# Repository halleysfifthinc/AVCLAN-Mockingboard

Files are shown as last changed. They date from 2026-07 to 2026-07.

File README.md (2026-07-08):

# AVCLAN Mockingboard

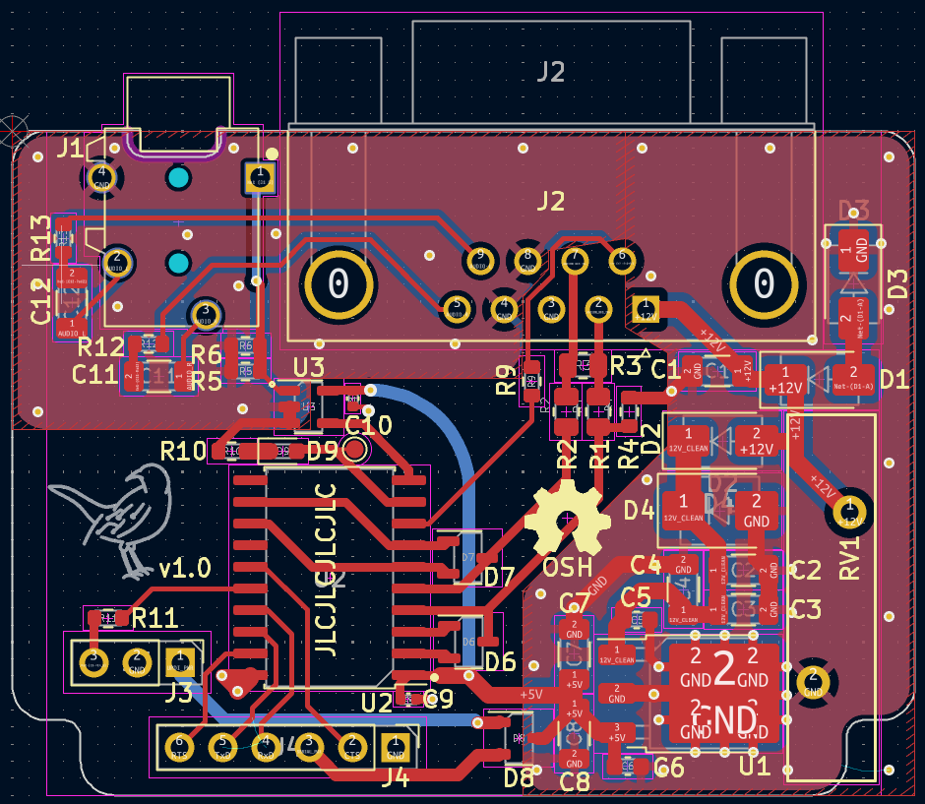
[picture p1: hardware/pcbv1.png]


This project adds an aux in to the stock head unit of compatible Toyota vehicles by emulating an external CD changer. The Mockingboard communicates with the head unit over the AVC-LAN bus, Toyota's name for their messaging protocol over the NEC (now Renesas) IEBus. Also included is a Wireshark dissector for IEBus and AVC-LAN. AVC-LAN is sparsely documented publicly; this dissector collects what's known from prior art alongside my own findings.

# Features:

- Select/switch between internal CD player and mockingboard by pressing the "CD" button (repeated presses toggle between internal and external CD players)
- Generally complete handling of physical interface (track next/prev, fast-forward/rewind, track/disk repeat and random; "scan" button and change disc buttons are currently unimplemented for lack of use/purpose)
- Play/pause, next/prev control of connected phones via headset functions (mimicing the button press on a wired headset; requires phone support and connection using a TRRS aux cable)

## Future plans (Mockingboard v2)

- Bluetooth functionality
  - "Scan" button repurposed to enter bluetooth pairing mode
  - Button actions (play/pause, track skip, ff/rw, \[disc\] repeat/shuffle) mapped to AVRCP
  - Song info/status (time, etc) relayed to head-unit (i.e. time display matches actual song/audio time)
- Redesigned hardware based on RPi Pico 2W (RP2350 + Bluetooth)
  - PIO used to implement:
    - AVCLAN comms
    - I2S audio
  - Dual audio input options (aux in, bluetooth)
    - Switched audio jack to sense aux plug presence
  - Audio codec with differential output (better rejection of electrical noise, e.g. from adjacent AVCLAN bus lines)
  - Switching regulator (easier assembly)
  - CAN transceiver
    - TX/RX connected to different diodes (or different pads of a single dual/multicolor LED package) for observability

# Helpful links/prior art:

- IEBus/AVCLAN decoder and message dumps (inc. a CD changer) for Sigrok
    - https://github.com/sigrokproject/sigrok-test/pull/22
    - https://github.com/sigrokproject/sigrok-dumps/pull/43
    - https://github.com/sigrokproject/libsigrokdecode/pull/106
- https://web.archive.org/web/20230319000356/http://softservice.com.pl/corolla/avc/avclan.php
- https://web.archive.org/web/20040617005106/http://www.interfacebus.com/Design_Connector_IEbus.html
- https://web.archive.org/web/2/https://old.pinouts.ru/Car-Stereo-Toyota-Lexus/Toyota_1990-2002_CD_Chang_pinout.shtml
- https://web.archive.org/web/20240519043021/https://pop.fsck.pl/hardware/toyota-corolla.html
- https://github.com/GadgetNutt/AVC-LAN-Module-Builder

# Firmware

### Building

#### With VS Code:

1. Install VS Code and Docker
    - Required extensions: Dev Containers
2. Open repo in VS code and wait for notification asking to re-open in dev container.
    - Wait for container to build and extensions to install
3. Select CMake build configuration
4. Start developing!

#### Natively/without VS Code Dev Containers
1. Install avr-gcc >= v13.1, binutils >= v2.39, cmake >= v3.24
2. Configure cmake with a hardware-target preset, `cmake --list-presets` to discover options
    - Trigger builds with e.g. `cmake --build out/build/attiny3216`
3. Start developing!

# Hardware

## First generation

See [here](hardware/mockingboard-v1/README.md) for details.

## Second generation

Under development!

# Protocol reverse-engineering

The "scripts/packet-analysis" folder contains a [Wireshark](https://www.wireshark.org/) [Lua plugin](https://www.wireshark.org/docs/wsdg_html_chunked/wsluarm.html) that defines a dissector for IEBUS and AVC-LAN messages.

The dissector's `known_devices` / `known_actions` tables are the source of truth
for AVC-LAN device and action names. `scripts/sync_avclan_enums.py` reconciles
the firmware's C++ `Device` / `Action` enums (and every reference under `src/`)
against them, matching by value so renamed values are propagated. It runs as a
pre-commit hook — the top-level CMake configure step points `core.hooksPath` at
`.githooks/`, so `cmake --preset …` activates it automatically (opt out with
`-DINSTALL_GIT_HOOKS=OFF`; `git commit --no-verify` bypasses one commit). The
hook only reports drift; run `scripts/sync_avclan_enums.py --fix` to apply, and
`--lint` to check that the dissector's own names are valid identifiers.

# License

The firmware for this project is licensed under the [GNU GPLv3](https://www.gnu.org/licenses/gpl-3.0.html). The AVR-Attiny3216 hardware target depends on a vendored [MIT](https://spdx.org/licenses/MIT) licensed [UART library](https://github.com/jnk0le/AVR-UART-lib), and the [MPL-2.0](https://www.mozilla.org/MPL/2.0/) licensed [avr-libstdcpp](https://github.com/modm-io/avr-libstdcpp/) C++ STL subset.
The hardware is licensed under the [Solderpad Hardware License v2.1](http://solderpad.org/licenses/SHL-2.1/), a
wraparound license to the [Apache License 2.0](https://apache.org/licenses/LICENSE-2.0.txt).

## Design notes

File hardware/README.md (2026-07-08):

# Hardware

## Cable harness

I ordered a [cable harness](https://www.amazon.com/dp/B01EUZ8CFU) from Amazon to acquire the head-unit side connector. I then cut the male end off a DB9 cable and connected the wires according to the following cable harness diagram:

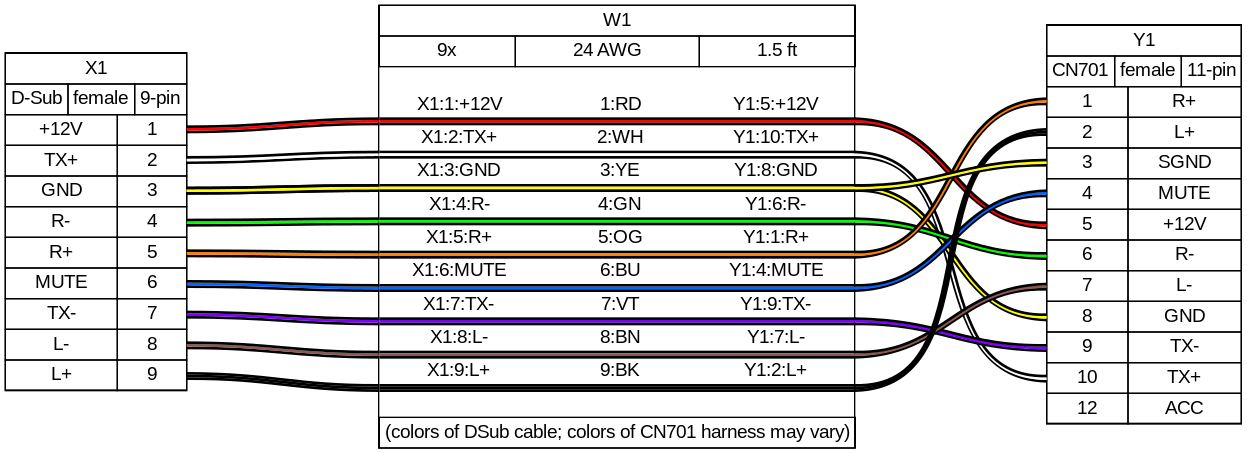
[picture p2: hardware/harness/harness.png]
cable diagram


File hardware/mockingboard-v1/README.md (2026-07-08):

# Hardware

I ordered the boards partially assembled from JLCPCB (to keep costs down, I ordered and soldered some non-standard/stocked parts myself.)

The non-populated/assembled BOM is:

| Mouser #: | Mfr. #: | Desc.: | Order Qty. | Unit Price (USD) |
| --- | --- | --- | --- | --- |
| 579-ATTINY3216-SNR  | ATTINY3216-SNR | 8-bit Microcontrollers - MCU 8-bit Microcontrollers - MCU 20MHz, 32KB, SOIC20, Ind 105C, Green, T&R | 1 | $1.27 |
| 523-L717SDE09PA4CH4 | L717SDE09PA4CH4F | D-Sub Standard Connectors D-Sub Standard Connectors D SUB R/A | 1 | $1.98 |
| 490-SJ-43514 | SJ-43514 | Phone Connectors Phone Connectors audio jack, 3.5 mm, rt, 4 conductor, through hole, 0 switches | 1 | $1.35 |
| 667-ERZ-V20D220 | ERZ-V20D220 | Varistors Varistors 22V 2000A ZNR SUR ABSORBER 20MM | 1 | $1.24 |
| 538-22-28-8093 | 22-28-8093 | Headers & Wire Housings Headers & Wire Housings 2.54MM BREAKAWAY RA 9 CKT Gold | 2 | $0.76 |
| 865-XC6701D502JR-G  | XC6701D502JR-G | LDO Voltage Regulators LDO Voltage Regulators 28V High Speed Voltage Regulator | 1 | $1.36 |
| 563-EXN-23350-BK | EXN-23350-BK | Enclosures, Boxes, & Cases Enclosures, Boxes, & Cases Extruded Aluminum Enclosure Black (1.4 X 2.7 X 1.9 In) | 1 | $14.40 |

An earlier version of the board* lacked cutouts in the corners to fit the ends of the intended housing, so I haven't used the listed enclosure (yet).

*Only version of the board I have ordered so far.

### Flashing

The CMake target `flash` uses the AVRDude utility using the "serialupdi" programmer type. I use a [USB => Serial converter](https://www.adafruit.com/product/5335) with the Rx and Tx lines connected, using one of the options described [by SpenceKonde here](https://github.com/SpenceKonde/AVR-Guidance/blob/master/UPDI/jtag2updi.md).

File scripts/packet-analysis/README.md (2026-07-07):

# Packet analysis with Wireshark

- Install the Lua IEBUS/AVCLAN packet dissector to the Wireshark Lua Plugins folder
    - Look in Help > About Wireshark dialog, Folders tab, "Personal Lua Plugins". It was `~/.local/lib/wireshark/plugins` for me, but it didn't exist until I manually created it.
    - Copy or link `avclan_plugin.lua` to the Wireshark Lua Pluginds folder
        - Linking is more convenient if modifying/developing the dissector
          `ln -s $(pwd)/avclan_plugin.lua ~/.local/lib/wireshark/plugins/avclan_plugin.lua`
- The bridge script ([extcap/avclan-pcap.py](extcap/avclan-pcap.py)) needs Python 3 and, for live capture only, [pyserial](https://pypi.org/project/pyserial/). Install pyserial so the `python3` that Wireshark runs can import it (e.g. `pip install pyserial`, or your distro's `python3-serial`). The `--convert` mode and the Wireshark interface listing work without it. (Alternatively, run the script via [uv](https://docs.astral.sh/uv/) — `uv run --script extcap/avclan-pcap.py …` — which resolves the inline PEP 723 dependency automatically; but the GUI extcap uses plain `python3`, so the install above is what makes capture work there.)

## Live capture (Wireshark GUI)

The easiest way to stream packets is as an [extcap](https://www.wireshark.org/docs/man-pages/extcap.html) interface, which appears right in Wireshark's capture list:

- Make the script executable and link it into Wireshark's **Personal Extcap path** (Help > About Wireshark, Folders tab — alongside the Lua plugin folder above):

      chmod +x extcap/avclan-pcap.py
      mkdir ~/.local/lib/wireshark/extcap
      ln -s "$(pwd)/extcap/avclan-pcap.py" ~/.local/lib/wireshark/extcap/avclan-pcap.py

- Restart Wireshark. **AVC-LAN (serial)** now shows up in the interface list. The script autodetects a USB-UART adapter; to override, open the interface's gear/options and set the serial port. Click the shark fin to start. Wireshark owns the process, so stopping the capture (or unplugging the adapter) shuts the bridge down cleanly.

## Live capture (command line)

If you prefer the pipe, the same script works as a plain producer:

    ./extcap/avclan-pcap.py --port /dev/ttyUSB0 | wireshark -k -i -

Omit `--port` (or pass `--port auto`) to autodetect the adapter.

## Converting a text log to pcap

The Mockingboard's text-mode REPL output (e.g. [msgdumps/myfile.txt](msgdumps/myfile.txt)) can be turned into a capture file offline:

    ./extcap/avclan-pcap.py --convert msgdumps/myfile.txt -o out.pcap

Use a `.pcapng` extension to get pcapng instead (requires `editcap`, which ships with Wireshark). With the Lua dissector installed, the result is recognized and dissected as IEBUS/AVCLAN packets.

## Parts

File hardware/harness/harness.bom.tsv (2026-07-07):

Id | Description | Qty | Unit | Designators
1 | Cable, 9 x 24 AWG | 1.5 | ft | W1
2 | Connector, CN701, female, 11 pins | 1 |  | Y1
3 | Connector, D-Sub, female, 9 pins | 1 |  | X1

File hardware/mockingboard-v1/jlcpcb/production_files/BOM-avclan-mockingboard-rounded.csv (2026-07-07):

Comment | Designator | Footprint | LCSC
SM6T15A | D4 | D_SMB | C118275
BAT54A,215 | D7 | SOT-23-3 | C130910
10u 50V | C2,C3,C4 | C_1206_3216Metric | C13585
SS210 | D1,D2 | D_SMA | C14996
1u 50V | C5,C6 | C_0603_1608Metric | C15849
10k | R4,R5,R6,R7,R8,R9 | R_0603_1608Metric | C17414
120 | R3 | R_0805_2012Metric | C17437
15 | R12,R13 | R_0603_1608Metric | C22810
KT-0603R | D9 | LED_0603_1608Metric | C2286
470 | R10,R11 | R_0603_1608Metric | C23179
4u7 | C10,C9 | C_0402_1005Metric | C23733
180 | R1,R2 | R_0805_2012Metric | C25270
1SMAF4742A | D3 | D_SMA | C3013762
BAT54C,215 | D6,D8 | SOT-23-3 | C37704
74LVC1G66 | U3 | SOT-23-5 | C5375974
3V3 | D10 | D_MiniMELF | C8056
1n 100V | C1 | C_1206_3216Metric | C9196
47u 10V | C11,C12,C7,C8 | C_1206_3216Metric | C96123

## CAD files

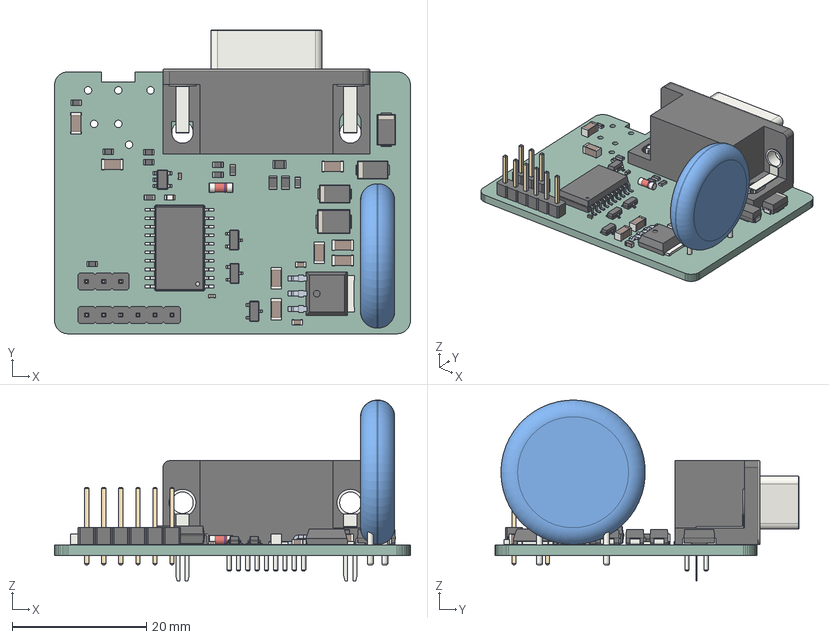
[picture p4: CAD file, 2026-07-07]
hardware/mockingboard-v1/avclan-mockingboard-rounded.step
53.0 x 45.2 x 26.9 mm
avclan-mockingboard-rounded PCB

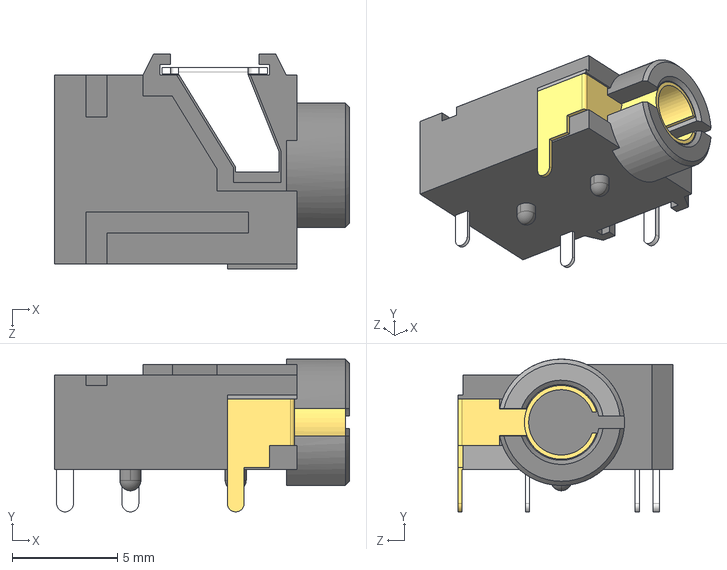
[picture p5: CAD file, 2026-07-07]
hardware/mockingboard-v1/CUI_DEVICES_SJ-43514.step
14.0 x 7.25 x 10.2 mm

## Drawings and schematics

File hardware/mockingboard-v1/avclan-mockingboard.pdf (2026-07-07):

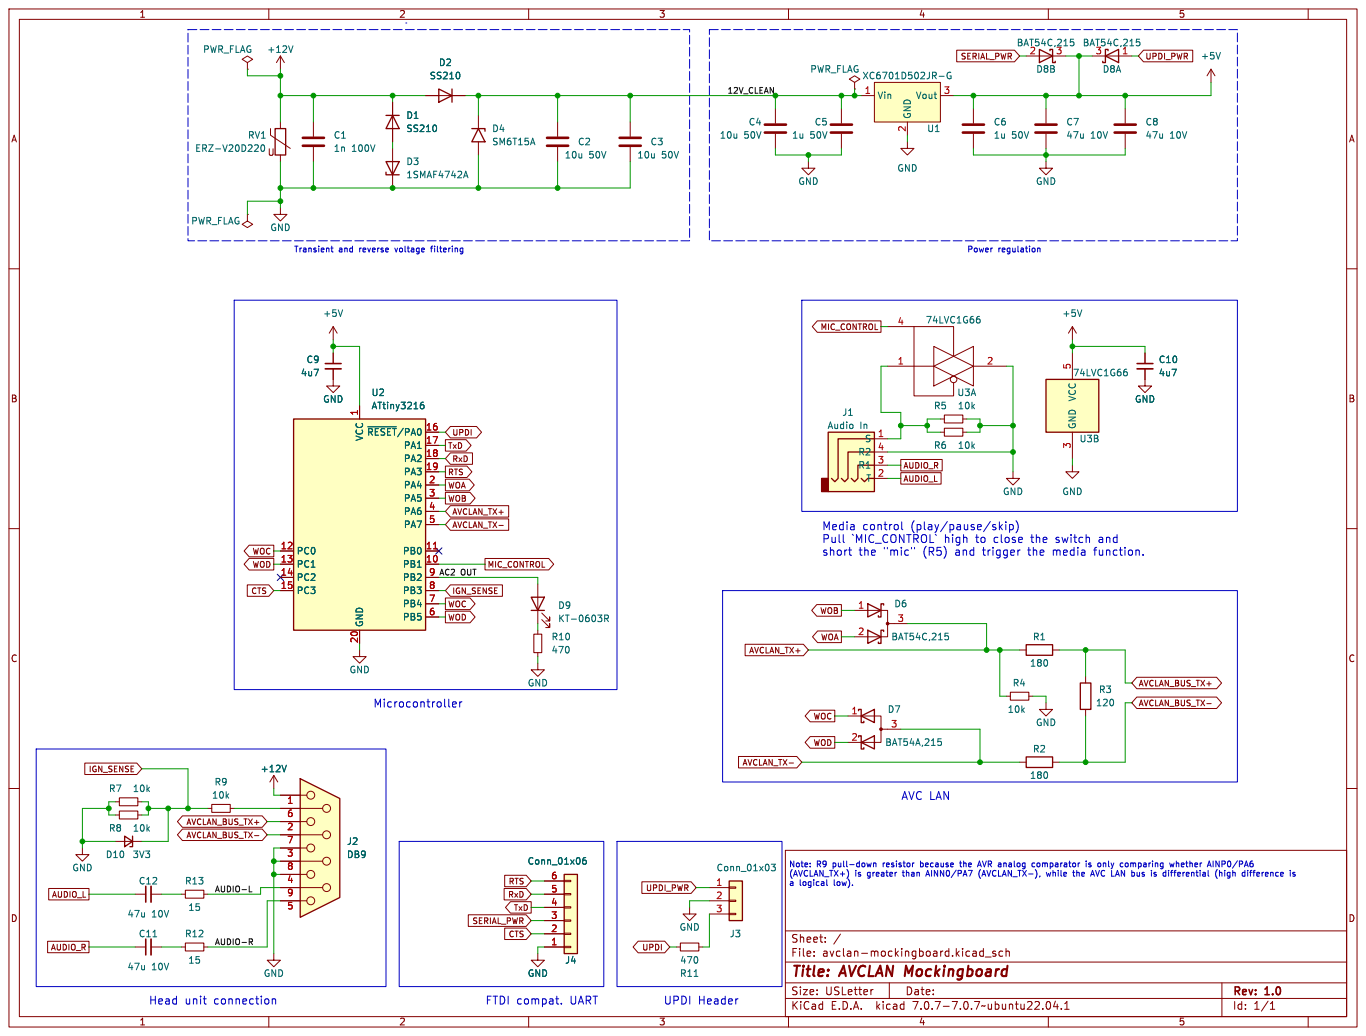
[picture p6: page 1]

1 PB1 10 PB0 11 PC0 12 PC1 13 PC2 14 PC3 15 ~{RESET}/PA016 PA1 17 PA2 18 PA3 19 PA4 2 GND 20 PA5 3 PA6 4 PA7 5 PB5 6 PB4 7 PB3 8 PB2 9 U2ATtiny3216 GND GND

File: avclan-mockingboard.kicad_sch Sheet: /
Id: 1/1 Title: AVCLAN Mockingboard

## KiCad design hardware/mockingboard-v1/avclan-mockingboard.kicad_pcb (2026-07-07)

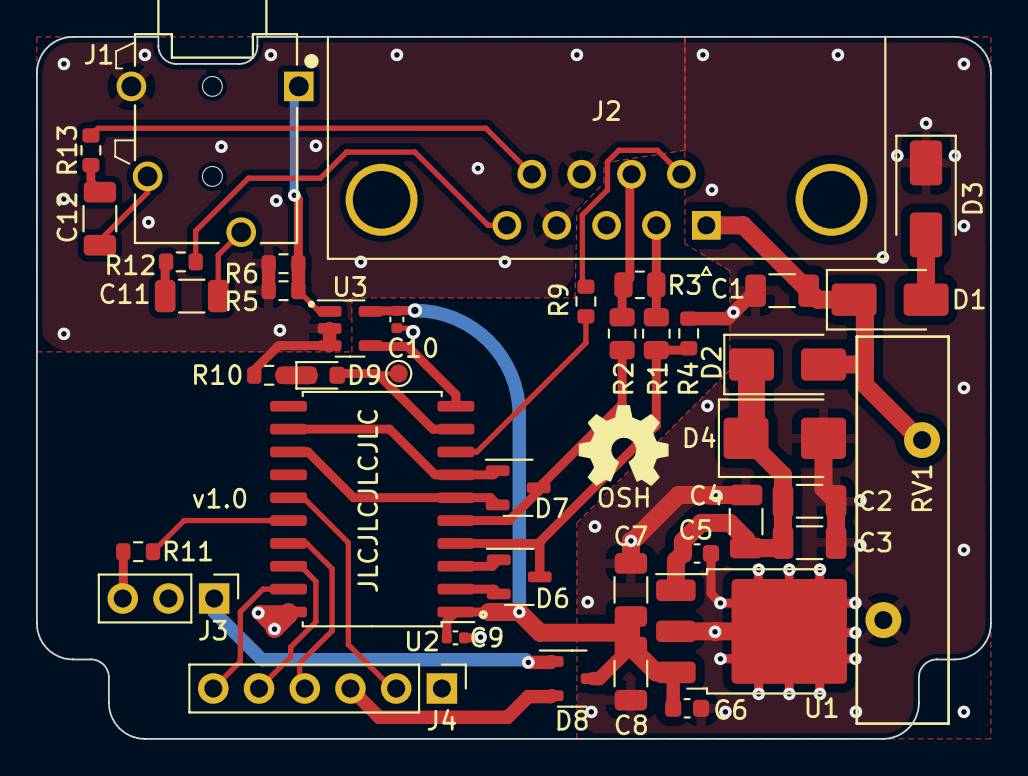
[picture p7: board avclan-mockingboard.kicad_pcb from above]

Board: 4 copper layers, 53.0 x 39.0 mm, 40 parts (0 on the bottom side), 33 nets.

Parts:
C1: 1n 100V; C_1206_3216Metric
C2, C3, C4: 10u 50V; C_1206_3216Metric
C5, C6: 1u 50V; C_0603_1608Metric
C7, C8, C11, C12: 47u 10V; C_1206_3216Metric
C9, C10: 4u7; C_0402_1005Metric
D1, D2: SS210; D_SMA
D3: 1SMAF4742A; D_SMA
D4: SM6T15A; D_SMB
D6, D8: BAT54C,215; SOT-23-3
D7: BAT54A,215; SOT-23-3
D9: KT-0603R; LED_0603_1608Metric
J1: Audio In; CUI_SJ-43514
J2: DB9; DSUB-9_Male_Horizontal_P2.77x2.84mm_EdgePinOffset7.70mm_Hou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
J3: Conn_01x03; PinHeader_1x03_P2.54mm_Vertical
J4: Conn_01x06; PinHeader_1x06_P2.54mm_Vertical
R1, R2: 180; R_0805_2012Metric
R3: 120; R_0805_2012Metric
R4, R5, R6, R9: 10k; R_0603_1608Metric
R10, R11: 470; R_0603_1608Metric
R12, R13: 15; R_0603_1608Metric
RV1: ERZ-V20D220; RV_Disc_D21.5mm_W5.1mm_P10mm
TP1: TestPoint; TestPoint_Pad_D1.0mm
U1: XC6701D502JR-G; TO-252-3_TabPin2
U2: ATtiny3216; SOIC-20W_7.5x12.8mm_P1.27mm
U3: 74LVC1G66; SOT-23-5

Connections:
+5V: C6.1, C7.1, C8.1, C9.1, C10.1, D8.3 (K), U1.3 (Vout), U2.1 (VCC), U3.5 (VCC)
+12V: C1.1, D1.1 (K), D2.2 (A), J2.1 (BAT), RV1.1
/12V_CLEAN: C2.1, C3.1, C4.1, C5.1, D2.1 (K), D4.1 (A1), U1.1 (Vin)
/AC2 OUT: D9.2 (A), TP1.1, U2.9 (PB2)
/AUDIO-L: J2.9 (R-), R13.1
/AUDIO-R: J2.5 (GND), R12.2
AUDIO_L: C12.1, J1.2 (T)
AUDIO_R: C11.1, J1.3 (R1)
AVCLAN_BUS_TX+: J2.2 (BUS+), R1.2, R3.2
AVCLAN_BUS_TX-: J2.7 (BUS-), R2.2, R3.1
AVCLAN_TX+: D6.3 (A), R1.1, R4.1, U2.4 (PA6)
AVCLAN_TX-: D7.3 (A), R2.1, U2.5 (PA7)
CTS: J4.2, U2.15 (PC3)
GND: C1.2, C2.2, C3.2, C4.2, C5.2, C6.2, C7.2, C8.2, C9.2, C10.2, D3.1 (K), D4.2 (A2), J1.4 (R2), J2.3 (L+), J2.4 (R+), J2.8 (L-), J3.2, J4.1, R4.2, R5.2, R6.2, R10.2, RV1.2, U1.2 (GND), U2.20 (GND), U3.2, U3.3 (GND)
MIC_CONTROL: U2.10 (PB1), U3.4
MUTE: R9.1, U2.8 (PB3)
unnamed: C11.2, R12.1
unnamed: C12.2, R13.2
unnamed: D1.2 (A), D3.2 (A)
unnamed: D9.1 (K), R10.1
unnamed: J1.1 (S), R5.1, R6.1, U3.1
unnamed: J2.6 (IGN/ACC), R9.2
unnamed: J3.3, R11.2
RTS: J4.6, U2.19 (PA3)
RxD: J4.4, U2.18 (PA2)
SERIAL_PWR: D8.2 (K), J4.3
TxD: J4.5, U2.17 (PA1)
UPDI: R11.1, U2.16 (~RESET/PA0)
UPDI_PWR: D8.1 (A), J3.1
WOA: D6.2 (K), U2.2 (PA4)
WOB: D6.1 (K), U2.3 (PA5)
WOC: D7.1 (K), U2.7 (PB4), U2.12 (PC0)
WOD: D7.2 (K), U2.6 (PB5), U2.13 (PC1)

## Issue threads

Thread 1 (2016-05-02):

Is it possible to buy this pcb ?

MartB, 2016-05-02:
Hey Sir,
I admire your work and i would really like to order the pcb because im not capable to build it myself. I just need a secondary aux input in my 2005 Toyota Aygo and i know it supports the AVC Lan protocol + has the required connectors. Sadly i have no idea what it would cost nor if it is possible for you.

Kind regards
Martin Böh

halleysfifthinc, 2016-06-14:
@MartinBoeh I didn't actually go to the trouble of making a pcb (both because I'm lazy and because I'm a broke college student :/ ) so I just used a breadboard

Closed 2024-08-23.

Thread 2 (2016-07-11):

Is it possible to upload your schematic and PCB?

shark300, 2016-07-11:
Dear halleysfifthinc,

I would like to build your circuit but I am a new guy in electronic. I understand your circuit but I am not sure. Can you upload your schematic and PCB? Thank you!

Best regards
Attila Hajdu

Closed 2024-08-23.

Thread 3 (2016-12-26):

Hello there.

arkroan, 2016-12-26:
I have just come across this interesting piece of work. I am looking for a way to read the steering wheel controls of the toyota avc LAN and possibly convert them to a resistor type or some other sort of signal.

I was wondering if you had any idea of the type of signals used for the controls since you were able to emulate a CD changer. Also if I am able to change your code to achieve this.

Thanks for your work and time.

Closed 2024-08-23.

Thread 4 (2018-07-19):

Newer Toyota models

Pejosonic, 2018-07-19:
Hi! I see that ou uploaded the code originally posted by Louis Frigon at SigmaObjects.
In his article he mentions that this code works for older Toyota HU. Also there's a link (broken) for a zip with a full versión for newer models.

Do you have this material?
Thank you very much!

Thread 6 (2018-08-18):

Internal 5 volt

hans-moleman22, 2018-08-18:
I started off with using the 5 volt supplied by the head unit. But that was problematic with its security system. Each power-up of the arduino nano triggers the security system and requires a PIN to reset.

A power-up happens whenever I start the engine.

In the end, I had to supply the nano with 5 volt from an external source.

Closed 2024-08-23.

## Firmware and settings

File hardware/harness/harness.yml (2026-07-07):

connectors:
  X1:
    type: D-Sub
    subtype: female
    pinlabels: [+12V, TX+, GND, R-, R+, MUTE, TX-, L-, L+]
  Y1:
    type: CN701
    subtype: female
    pins: [1, 2, 3, 4, 5, 6, 7, 8, 9, 10, 12]
    pinlabels: [R+, L+, SGND, MUTE, +12V, R-, L-, GND, TX-, TX+, ACC]

cables:
  W1:
    wirecount: 9
    length: 1.5 ft
    gauge: 24 AWG
    colors: [RD, WH, YE, GN, OG, BU, VT, BN, BK]
    notes: (colors of DSub cable; colors of CN701 harness may vary)

connections:
  - - X1: [1-9]
    - W1: [1-9]
    - Y1: [5, 10, 8, 6, 1, 4, 9, 7, 2]
  - - X1: 3
    - W1: 3
    - Y1: 3

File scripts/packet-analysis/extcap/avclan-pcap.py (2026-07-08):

#!/usr/bin/env python3
# /// script
# requires-python = ">=3.9"
# dependencies = ["pyserial"]
# ///
"""AVC-LAN Mockingboard -> pcap bridge for Wireshark.

Three modes, one script:

  * extcap  - invoked by Wireshark; appears as the "AVC-LAN (serial)" capture
              interface. Wireshark owns the process lifecycle, so stopping the
              capture (or unplugging the adapter) tears everything down cleanly.
  * pipe    - run by hand: `./avclan-pcap.py --port /dev/ttyUSB0 | wireshark -k -i -`
  * convert - turn a text-mode serial log into a pcap file offline:
              `./avclan-pcap.py --convert msgdumps/myfile.txt -o out.pcap`

The firmware emits frames over serial at 1.2 Mbaud, 8N1, in one of two formats
(selected at the REPL). This script understands both and emits pcap with
linktype 162 (USER15), matching the avclan_plugin.lua dissector.

Discovery (the extcap query phases), `--convert`, and argument handling run on
the standard library alone, so the script keeps a plain `python3` shebang and
Wireshark can always exec it -- Wireshark launches extcaps with a minimal PATH,
which is why a `uv` shebang here would make the interface vanish from the GUI.
The one dependency, `pyserial`, is only needed to actually read the serial port:
capture fails with a clear message if it is missing. Install it normally (so the
`python3` invocation Wireshark uses can find it), or run the script via
`uv run --script` to have uv resolve the inline dependency above.
"""

import argparse
import os
import re
import shutil
import signal
import struct
import subprocess
import sys
import tempfile
import time
from datetime import datetime, timedelta

# ---------------------------------------------------------------------------
# pcap on-the-wire format. Mirrors the old Julia PcapTools output exactly:
# nanosecond magic, snaplen 64, linktype 162 (DLT_USER15 / wtap.USER15).
# ---------------------------------------------------------------------------
PCAP_MAGIC_NS = 0xA1B23C4D
SNAPLEN = 64
LINKTYPE_USER15 = 162

PCAP_GLOBAL_HEADER = struct.pack(
    "<IHHiIII",
    PCAP_MAGIC_NS,  # magic (nanosecond resolution, little-endian)
    2,              # version major
    4,              # version minor
    0,              # thiszone
    0,              # sigfigs
    SNAPLEN,        # snaplen
    LINKTYPE_USER15,
)

# Serial framing bytes emitted by AVCLAN_printframe(..., binary=1).
DLE = 0x10  # start of a binary frame
ETB = 0x17  # end of a binary frame (followed by \n; CR tolerated, see below)
MAX_DATA_LEN = 32  # AVCLAN payload cap; longer "length" => bad framing

BAUD = 1_200_000

# USB-UART bridge vendor IDs worth preferring during autodetect.
PREFERRED_VIDS = {
    0x0403,  # FTDI
    0x10C4,  # Silicon Labs CP210x
    0x1A86,  # WCH CH340/CH341
    0x067B,  # Prolific PL2303
}


# ---------------------------------------------------------------------------
# pcap writing
# ---------------------------------------------------------------------------
def write_global_header(out):
    out.write(PCAP_GLOBAL_HEADER)
    out.flush()


def write_record(out, ts_ns, payload):
    sec, nsec = divmod(ts_ns, 1_000_000_000)
    out.write(struct.pack("<IIII", sec, nsec, len(payload), len(payload)))
    out.write(payload)
    out.flush()


# ---------------------------------------------------------------------------
# Binary frame extraction (live capture / pipe modes)
#
# Length-based rather than line-based: the firmware does not escape payload
# bytes, so a data byte of 0x0A/0x10/0x17 must not be allowed to split a frame.
# We locate a DLE, read the fixed 7-byte header, trust its `length` field, then
# require an ETB exactly where it should be -- resyncing on any mismatch.
# ---------------------------------------------------------------------------
def extract_frames(buf):
    """Pull complete frame payloads out of `buf`, consuming what it returns.

    Yields the dissector-ready payload for each frame:
    [is_unicast, ctrl_hi, ctrl_lo, periph_hi, periph_lo, control, length, data...]
    Leaves any trailing partial frame in `buf` for the next call.
    """
    frames = []
    pos = 0
    while True:
        dle = buf.find(DLE, pos)
        if dle == -1:
            buf.clear()
            return frames
        # Need DLE + 7 header bytes (the last of which is `length`).
        if len(buf) < dle + 8:
            del buf[:dle]
            return frames
        length = buf[dle + 7]
        if length > MAX_DATA_LEN:
            pos = dle + 1  # spurious DLE; resync past it
            continue
        etb = dle + 8 + length  # index where ETB must sit
        if len(buf) < etb + 1:
            del buf[:dle]
            return frames
        if buf[etb] != ETB:
            pos = dle + 1  # framing mismatch; this DLE was not a real start
            continue
        frames.append(bytes(buf[dle + 1:etb]))  # 7 header bytes + data
        pos = etb + 1
        while pos < len(buf) and buf[pos] in (0x0D, 0x0A):
            pos += 1  # swallow the trailing \r\n
        del buf[:pos]
        pos = 0


# ---------------------------------------------------------------------------
# Serial helpers (lazy pyserial import)
# ---------------------------------------------------------------------------
def detect_port():
    """Best-guess serial device, or None. Prefers known USB-UART bridges.

    Uses pyserial's enumeration when available, but falls back to a stdlib
    glob so the extcap config dialog still offers a sensible default before
    pyserial has been pulled in.
    """
    try:
        from serial.tools import list_ports
    except ImportError:
        import glob
        cands = sorted(glob.glob("/dev/ttyUSB*")) + sorted(glob.glob("/dev/ttyACM*"))
        return cands[0] if cands else None

    ports = list(list_ports.comports())
    if not ports:
        return None

    def score(p):
        s = 0
        if p.vid in PREFERRED_VIDS:
            s += 10
        dev = p.device or ""
        if "ttyUSB" in dev:
            s += 3
        elif "ttyACM" in dev:
            s += 2
        return s

    ports.sort(key=score, reverse=True)
    return ports[0].device


def ensure_pyserial():
    """Fail with a clear message if pyserial (capture-only) is unavailable."""
    try:
        import serial  # noqa: F401
    except ImportError:
        sys.exit("error: capture requires pyserial, which is not installed.\n"
                 "Install it (e.g. `pip install pyserial`), or run this script via "
                 "`uv run --script` to pull in the inline dependency.")


def resolve_port(requested):
    """Map a requested port (possibly None/"auto") to a concrete device."""
    if requested and requested != "auto":
        return requested
    port = detect_port()
    if not port:
        sys.exit("error: no serial port given and none could be autodetected "
                 "(pass --port /dev/ttyUSBx)")
    return port


def open_serial(port):
    import serial  # lazy: only the serial modes need it

    # Flow control fully off: the binary payload can legitimately contain
    # 0x11 (XON) / 0x13 (XOFF), which a flow-controlled link would eat.
    return serial.Serial(
        port,
        BAUD,
        timeout=0.2,  # short, so signal flags get checked promptly
        xonxoff=False,
        rtscts=False,
        dsrdtr=False,
    )


# ---------------------------------------------------------------------------
# Capture (extcap + pipe)
# ---------------------------------------------------------------------------
_stop = False


def _request_stop(signum, frame):
    global _stop
    _stop = True


def run_capture(out, port):
    """Stream frames from the serial port to `out` until told to stop."""
    ensure_pyserial()  # re-execs under uv if pyserial is missing
    import serial  # for SerialException

    port = resolve_port(port)
    try:
        ser = open_serial(port)
    except serial.SerialException as e:
        sys.exit("error: could not open %s: %s" % (port, e))

    # Put the firmware into binary-frame mode (REPL 'X').
    try:
        ser.write(b"X")
    except serial.SerialException:
        pass

    buf = bytearray()
    try:
        write_global_header(out)
        while not _stop:
            try:
                chunk = ser.read(ser.in_waiting or 1)
            except serial.SerialException:
                break  # adapter went away -> stop cleanly
            if not chunk:
                continue
            buf.extend(chunk)
            for payload in extract_frames(buf):
                write_record(out, time.time_ns(), payload)
    except (BrokenPipeError, OSError):
        pass  # Wireshark closed the fifo/pipe -> we're done
    finally:
        ser.close()


# ---------------------------------------------------------------------------
# Convert (offline text log -> pcap), replacing Julia avclan_text_to_pcap
# ---------------------------------------------------------------------------
TIME_RE = re.compile(r"^(\d{1,2}):(\d{2}):(\d{2})\.(\d+)$")


def parse_text_line(line, base_date):
    """Parse one text-mode log line.

    Returns (ts_ns_or_None, payload) or None if the line is not a frame.
    Line format (whitespace separated):
        [HH:MM:SS.mmm] is_unicast controller peripheral control length data...
    with the numeric fields in C-style notation (0x.. or plain decimal).
    """
    tokens = line.split()
    if len(tokens) < 5:
        return None

    ts_ns = None
    m = TIME_RE.match(tokens[0])
    if m:
        h, mn, s, frac = m.groups()
        micros = int(frac.ljust(6, "0")[:6])
        try:
            dt = datetime(base_date.year, base_date.month, base_date.day,
                          int(h), int(mn), int(s))
        except ValueError:
            return None
        ts_ns = int(dt.timestamp()) * 1_000_000_000 + micros * 1000
        tokens = tokens[1:]

    if len(tokens) < 5:
        return None
    try:
        is_unicast = int(tokens[0], 0)
        controller = int(tokens[1], 0)
        peripheral = int(tokens[2], 0)
        control = int(tokens[3], 0)
        length = int(tokens[4], 0)
    except ValueError:
        return None

    data_tokens = tokens[5:]
    if length > MAX_DATA_LEN or len(data_tokens) != length:
        return None
    try:
        data = bytes(int(d, 0) & 0xFF for d in data_tokens)
    except ValueError:
        return None

    payload = bytes([
        is_unicast & 0xFF,
        (controller >> 8) & 0xFF, controller & 0xFF,
        (peripheral >> 8) & 0xFF, peripheral & 0xFF,
        control & 0xFF,
        length & 0xFF,
    ]) + data
    return ts_ns, payload


def run_convert(infile, output):
    # Date comes from the log's mtime (the lines only carry a wall-clock time);
    # falls back to today if that is unavailable.
    try:
        base_date = datetime.fromtimestamp(os.path.getmtime(infile))
    except OSError:
        base_date = datetime.now()

    want_pcapng = bool(output) and output.endswith(".pcapng")
    tmp_path = None
    if want_pcapng:
        fd, tmp_path = tempfile.mkstemp(suffix=".pcap")
        out = os.fdopen(fd, "wb")
        close_out = True
    elif output:
        out = open(output, "wb")
        close_out = True
    else:
        out = sys.stdout.buffer
        close_out = False

    last_ts = None
    count = 0
    try:
        write_global_header(out)
        with open(infile, "r") as f:
            for line in f:
                parsed = parse_text_line(line, base_date)
                if parsed is None:
                    continue
                ts_ns, payload = parsed
                if ts_ns is None:
                    # No timestamp on this line; nudge past the previous one so
                    # ordering is preserved (mirrors the old Julia behaviour).
                    base = last_ts if last_ts is not None else time.time_ns()
                    ts_ns = base + 1000
                write_record(out, ts_ns, payload)
                last_ts = ts_ns
                count += 1
    finally:
        if close_out:
            out.close()

    if want_pcapng:
        editcap = shutil.which("editcap")
        if editcap:
            subprocess.run([editcap, "-F", "pcapng", tmp_path, output], check=True)
            os.unlink(tmp_path)
        else:
            fallback = output[: -len(".pcapng")] + ".pcap"
            shutil.move(tmp_path, fallback)
            print("warning: editcap not found; wrote pcap to %s instead of %s"
                  % (fallback, output), file=sys.stderr)
            output = fallback

    if output:
        print("wrote %d frames to %s" % (count, output), file=sys.stderr)


# ---------------------------------------------------------------------------
# extcap argument phases
# ---------------------------------------------------------------------------
def extcap_interfaces():
    print("extcap {version=1.0}{help=https://github.com/}"
          "{display=AVC-LAN Mockingboard}")
    print("interface {value=avclan}{display=AVC-LAN (serial)}")


def extcap_dlts():
    print("dlt {number=%d}{name=USER15}{display=AVC-LAN / IEBus}" % LINKTYPE_USER15)


def extcap_config():
    default = detect_port() or "auto"
    print('arg {number=0}{call=--port}{display=Serial port}{type=string}'
          '{tooltip=Serial device path, or "auto" to autodetect}'
          '{default=%s}' % default)


# ---------------------------------------------------------------------------
# main
# ---------------------------------------------------------------------------
def main():
    parser = argparse.ArgumentParser(add_help=True)
    # extcap discovery/lifecycle flags (Wireshark-driven)
    parser.add_argument("--extcap-interfaces", action="store_true")
    parser.add_argument("--extcap-dlts", action="store_true")
    parser.add_argument("--extcap-config", action="store_true")
    parser.add_argument("--extcap-interface")
    parser.add_argument("--extcap-version")
    parser.add_argument("--capture", action="store_true")
    parser.add_argument("--fifo")
    parser.add_argument("--extcap-control-in")
    parser.add_argument("--extcap-control-out")
    # shared / CLI
    parser.add_argument("--port", help='serial device, or "auto"')
    parser.add_argument("--convert", metavar="LOGFILE",
                        help="convert a text-mode serial log to pcap")
    parser.add_argument("-o", "--output",
                        help="output file for --convert (.pcap or .pcapng); "
                             "stdout if omitted")
    args, _ = parser.parse_known_args()

    if args.extcap_interfaces:
        extcap_interfaces()
        return
    if args.extcap_dlts:
        extcap_dlts()
        return
    if args.extcap_config:
        extcap_config()
        return
    if args.convert:
        run_convert(args.convert, args.output)
        return

    signal.signal(signal.SIGINT, _request_stop)
    signal.signal(signal.SIGTERM, _request_stop)

    if args.capture:
        if not args.fifo:
            sys.exit("error: --capture requires --fifo")
        with open(args.fifo, "wb") as fifo:
            run_capture(fifo, args.port)
        return

    # No mode flags: behave as a plain pipe into `wireshark -k -i -`.
    run_capture(sys.stdout.buffer, args.port)


if __name__ == "__main__":
    try:
        main()
    except BrokenPipeError:
        # Reader (Wireshark) went away; exit quietly without a traceback.
        try:
            sys.stdout.close()
        except Exception:
            pass
        os._exit(0)

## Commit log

2015-07-23 Merged Marcin's AVC-LAN driver
2015-07-23 Updated Makefile for new driver/main file
2015-07-24 Removed old schematics
2015-07-27 Message read now works
    [timing,16MHz,1000-err0.csv, timing,16MHz,1000.csv, timing,16MHz,2000.csv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]
2015-07-28 Data visuals/research
    [timing,16MHz,1000.csv, timing,16MHz,1000.xlsx]
2023-08-03 Replace Timer1 with periodic interrupt timer from the RTC
2023-08-03 Update to use attiny1616 AC2 and TCB1
    - Change AVC output enable/disable to only change input/output of pin 7;
    only one pin should need to be used to send (i.e. actual differential
    signaling isn't being used, therefore, we can achieve the necessary
    (single-ended) differential voltage using only one pin, leaving the
    other outputting low)
    - Use virtual ports to enable setting output status with single
    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
2023-08-20 Remove LED functionality
2023-08-20 Remove old/irrelevant files
    [timing,16MHz,1000-err0.csv, timing,16MHz,1000.csv, timing,16MHz,1000.xlsx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]
2023-08-20 Switch PROGMEM related uses to regular flash (flat address space in avrxmega3)
2023-08-20 Indent case labels
2023-08-21 Use alternate UART TxD/RxD pins
2023-08-22 Switch to CMake
2023-08-23 Enable AC2_OUT for LED
2023-09-03 Switch master/slave replacements to OSHWA recommended controller/peripheral
2023-09-03 Change sendbit timer config to optimize function length (insns)
2023-09-10 Setup timing better (fuses, clock speed, TCB clock speed)
2023-09-10 Update/fix pin levels for new transmission design
2023-09-12 Add printhex12 function
2023-09-15 Add binary printing and reading/parsing from serial
2023-09-16 Fix UART 2x speed config
2023-09-16 Fix printBinary flag
2023-09-17 Add @jnk0le AVR-UART-lib master
2023-10-16 Fix binary printframe
2023-10-28 Boost UART speed
2023-10-28 Optimize binary printframe (reduce number of RS232_print calls)
2023-10-28 Refactor frame handling and response code
2024-08-23 Add Wireshark packet dissector plugin and associated tools
2024-08-23 Add circuit board and wiring harness
    [BOM-avclan-mockingboard-rounded.csv, CUI_DEVICES_SJ-43514.step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]
2025-10-09 Expand Wireshark packet dissector support
2026-05-05 Refactor message handling switch tree
2026-05-05 Refactor error handling in read/send frame
2026-05-08 Substantially refactor ~everything to separate concerns and improve flow clarity
    Highlights:
    - Remove all use of malloc and friends
    - Refactor message handling functions to work with references
    - Move core message read => triage => respond logic loop to main
    function
    - Improve message triage and support follow-up messages
    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
2026-05-12 Group pointer increments for better assembly (in recent GCC)
2026-05-16 Tighten PIT interrupt and avoid some BCD edge-cases
2026-05-16 Rename field broadcast => is_unicast
    Improves readability and logical flow clarity
2026-05-16 Flatten msg triage switches to dispatch on first 3 bytes together (as uint32_t)
2026-05-16 chown usb device after creating container
2026-06-12 Refactor frame dissector to improve readability/future expansion
2026-06-12 Refactor cmake/presets for easier serial usb device selection
2026-06-13 Shift state machine from main loop to driver file
2026-06-15 Fix track change logic (track is/should be serialized as BCD)
2026-06-19 Correctly respond to button actions (CMD_SW state report)
2026-06-19 use direct instead of pointer access for cd track/min/sec
2026-06-19 Delay starting status timer until state has been normalized
2026-06-21 Switch to a python based [streaming] packet capture setup
2026-06-22 reorg hardware folder for v2 dev
    [BOM-avclan-mockingboard-rounded.csv, CUI_DEVICES_SJ-43514.step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]
2026-06-23 Update devcontainer startup to consistently chown passed-thru usb devices
2026-06-25 Port Queue to C++
    Some knock-on changes to keep a simple design:
    - Bake the data array into AVCLAN_frame_t
    - Bundle the response/reaction with AVCLAN_frame_t
    - (Needed to maintain correct/simple ownership semantics with the
    cache and outgoing/incoming queues)
    - Switch status frame update ticks to use a regular
    cache-originating/owned frame
2026-06-27 Parameterise `Peripheral` by its `Device`s and add `CDChanger` as one
2026-07-06 Port Frame object to C++
2026-07-06 fixup error switch flow
2026-07-06 Shift Device/Action enums to avclan.h
2026-07-06 Establish the Lua dissector action/device/etc tables as authoritative
2026-07-07 Consistently mark frame owners
2026-07-07 Complete the switch to jnk0le uart lib
2026-07-08 Fix miscellaneous bugs identified by Claude
    [avclan-pcap.py]
2026-07-16 Only check tracked files and don't print on empty lint
2026-07-16 Unify frame metadata setting (addrs and owning_device)
2026-07-17 Switch to using references where possible
2026-07-17 Redesign (simplify) top-level avclan interface to use expected/nullable unique_ptr
    - Peripheral::read/send now return `expected<unique_ptr<Frame>, Error>`
    for a unified success/error interface.
    - Peripheral::route returns `expected<unique_ptr<Frame>, Error>` to
    distinguish intent: (intentional) non-response vs unable to respond
    - Other functions with optional message semantics (handle,poll,react)
    return a unique_ptr whose ownership-state indicates response intent
    (i.e. send new message)
    Bundled necessary changes:
    - Switch Frame allocation from global to local (enabled via member
    function new/delete)
    - Add new header-library tl::expected to shim avr-libstdcpp
    Unrelated: Defensive `continu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
2026-07-21 Not all error conditions print a message
2026-08-01 Restore dynamic from device in function change resp
2026-08-13 Tighten up non-reading TCB0 ISR timing
2026-08-13 Max the UART TX buffer size
2026-08-14 Speed up Frame printing to (finally) solve missing AVCLAN bus frames
2026-08-14 react to [disk] scan button presses
2026-08-19 Improve `stdio_write_nonblock` perf and indicator printing
